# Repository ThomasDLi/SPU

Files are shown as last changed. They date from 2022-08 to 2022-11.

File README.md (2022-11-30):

# SPU (work in progress)
Sigma Processing Unit: an indelendently driveable 8-bit CPU designed by myself, inspired by the interface used to communicate with the 6502 microprocesser and Ben Eater's 8 bit cpu. I have also written an article on this project! https://thomasdli.notion.site/Designing-An-8-Bit-CPU-Thomas-Li-f7da20de04c84557adcc27d55567141a



(pcb)



(pcb layout)



(zoomed out screenshot of the schematic)

## Specs
- 8 bit address bus for a total of 256 memory locations (including program counter, which starts at address 0, and can also go up to 255)
- 8 bit data bus

- full 8 bit load immediate instructions supported

- 2 general purpose registers
- add/subtraction for ALU with conditional junps for both Zero and Carry flags

- 16 instructions avaliable currently with minimal edits required in order to increase up to 128 instructions
- 16 clock cycles required for each instruction

- R/W flag for memory

- support for external I/O

- turing complete

- maximum clock speed of idfk

### instruction set

- still writing firmware

## todo

- write firmware
- design a VIA for the processor for I/O

## downloading design

This CPU was designed using 74LS series ICs from Texas Instruments, and was made using Autodesk Eagle.

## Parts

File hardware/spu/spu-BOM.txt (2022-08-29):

Partlist exported from /Users/thomas/Documents/EAGLE/projects/spu/spu-schematic.sch at 2022-08-28 8:30 PM

Part    Value    Device    Package Description                          POPULARITY
ADDRESS          PINHD-1X8 1X08    PIN HEADER                           67        
DATA             PINHD-1X8 1X08    PIN HEADER                           67        
HALT             PINHD-1X1 1X01    PIN HEADER                           64        
IC1     74LS173N 74LS173N  DIL16   4-bit D type REGISTER, 3-state       0         
IC2     74LS173N 74LS173N  DIL16   4-bit D type REGISTER, 3-state       0         
IC3     74LS173N 74LS173N  DIL16   4-bit D type REGISTER, 3-state       0         
IC4     74LS173N 74LS173N  DIL16   4-bit D type REGISTER, 3-state       0         
IC5     74AC245N 74AC245N  DIL20   Octal BUS TRANSCEIVER, 3-state       0         
IC6     74AC245N 74AC245N  DIL20   Octal BUS TRANSCEIVER, 3-state       0         
IC7     74LS173N 74LS173N  DIL16   4-bit D type REGISTER, 3-state       0         
IC8     74LS173N 74LS173N  DIL16   4-bit D type REGISTER, 3-state       0         
IC9     74AC245N 74AC245N  DIL20   Octal BUS TRANSCEIVER, 3-state       0         
IC10    74AC245N 74AC245N  DIL20   Octal BUS TRANSCEIVER, 3-state       0         
IC11    74LS86N  74LS86N   DIL14   Quad 2-input EXCLUSIVE-OR (XOR) gate 0         
IC12    74LS283N 74LS283N  DIL16   4-bit binary FULL ADDER, fast carry  0         
IC13    74LS283N 74LS283N  DIL16   4-bit binary FULL ADDER, fast carry  0         
IC14    74LS86N  74LS86N   DIL14   Quad 2-input EXCLUSIVE-OR (XOR) gate 0         
IC15    74LS173N 74LS173N  DIL16   4-bit D type REGISTER, 3-state       0         
IC16    74S02N   74S02N    DIL14   Quad 2-input NOR gate                0         
IC17    74LS08N  74LS08N   DIL14   Quad 2-input AND gate                0         
IC18    74AC245N 74AC245N  DIL20   Octal BUS TRANSCEIVER, 3-state       0         
IC19    74LS173N 74LS173N  DIL16   4-bit D type REGISTER, 3-state       0         
IC20    74LS173N 74LS173N  DIL16   4-bit D type REGISTER, 3-state       0         
IC21    74AC245N 74AC245N  DIL20   Octal BUS TRANSCEIVER, 3-state       0         
IC22    74LS161  74HCT160N DIL16   Synchronous 4-bit COUNTER            0         
IC23    74LS161  74HCT160N DIL16   Synchronous 4-bit COUNTER            0         
IC24    74LS173N 74LS173N  DIL16   4-bit D type REGISTER, 3-state       0         
IC25    74LS173N 74LS173N  DIL16   4-bit D type REGISTER, 3-state       0         
IC26    74AC245N 74AC245N  DIL20   Octal BUS TRANSCEIVER, 3-state       0         
IC27    74LS04N  74LS04N   DIL14   Hex INVERTER                         0         
IC28    74LS04N  74LS04N   DIL14   Hex INVERTER                         0         
IC29    74LS04N  74LS04N   DIL14   Hex INVERTER                         0         
IC30    74LS161  74HC160N  DIL16   Synchronous 4-bit COUNTER            0         
IC31    74LS04N  74LS04N   DIL14   Hex INVERTER                         0         
JP2     CLOCK/RW PINHD-1X2 1X02    PIN HEADER                           98        
POWER   5V/GND   PINHD-1X2 1X02    PIN HEADER                           98        
U1      AT28C256 AT28C256  DIL28-6 EEPROM 32Kx8 256k bit                          
U2      AT28C256 AT28C256  DIL28-6 EEPROM 32Kx8 256k bit                          
U3      AT28C256 AT28C256  DIL28-6 EEPROM 32Kx8 256k bit

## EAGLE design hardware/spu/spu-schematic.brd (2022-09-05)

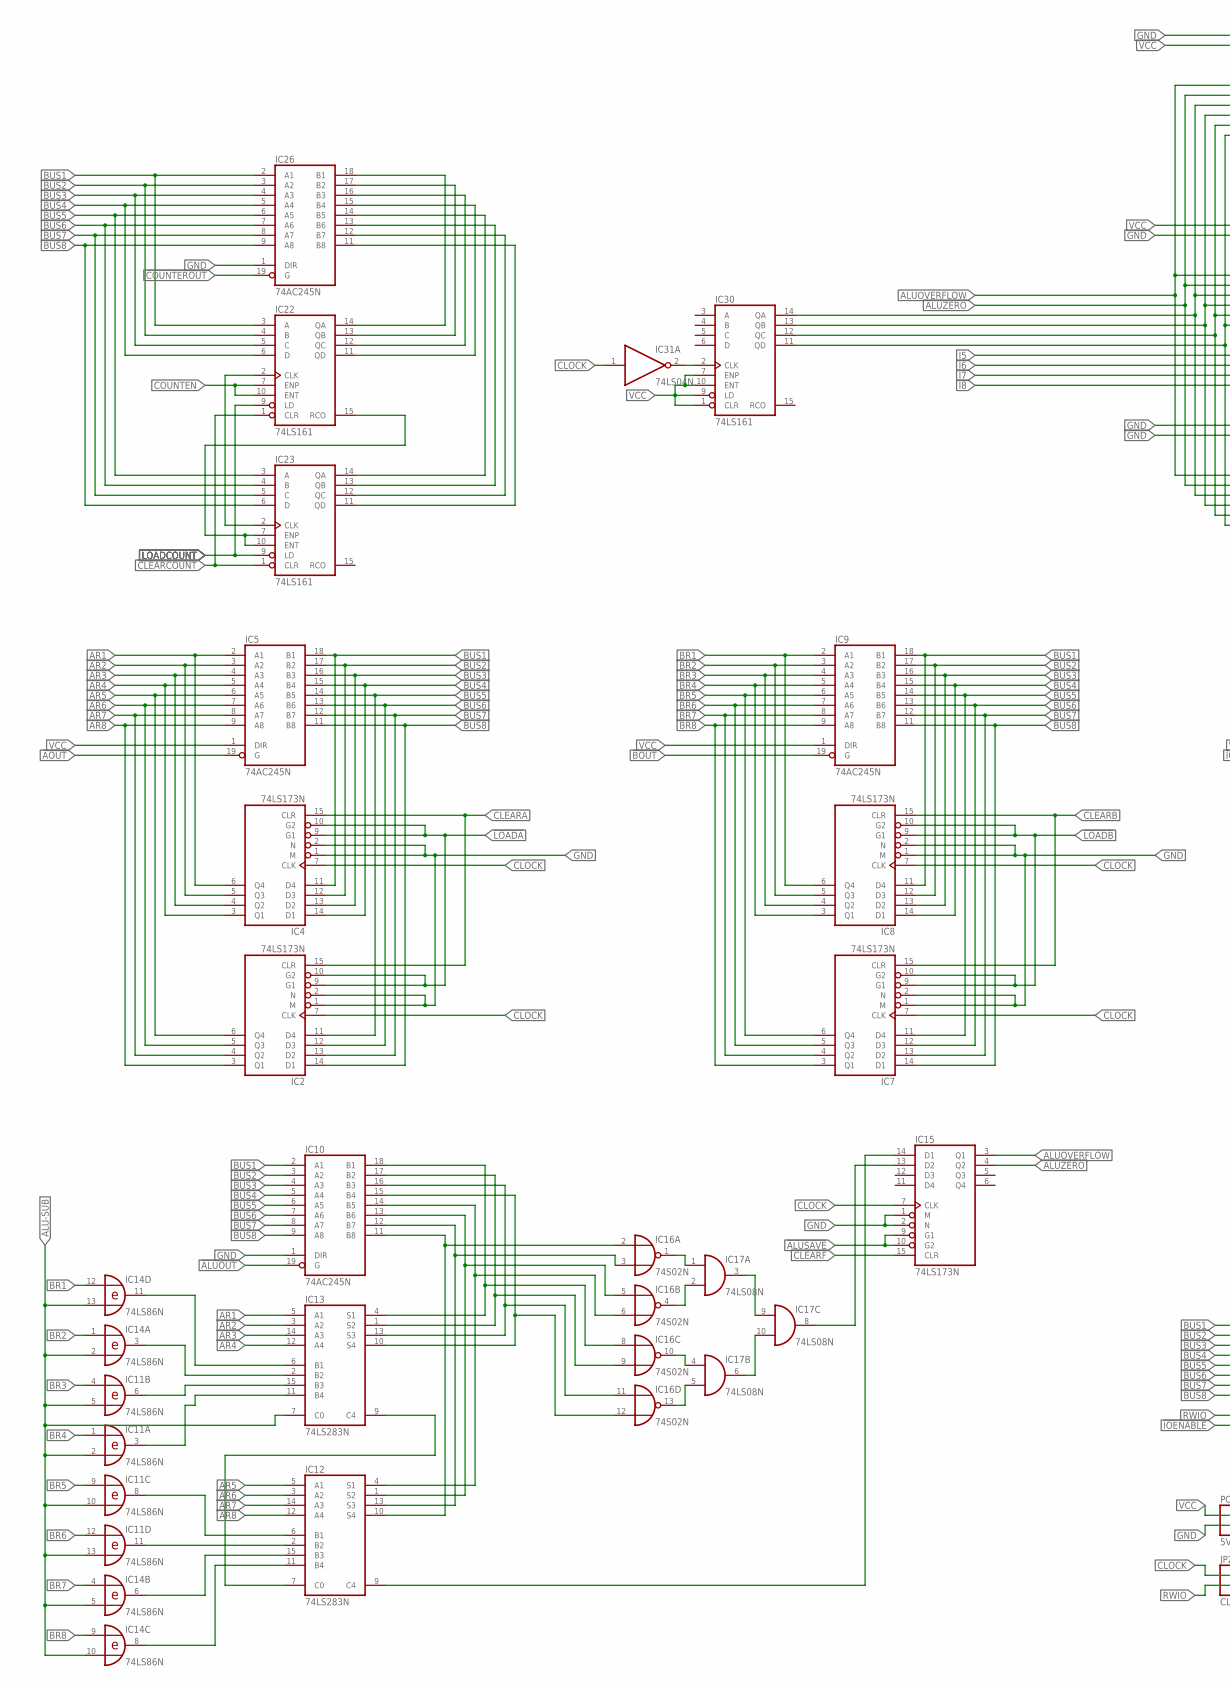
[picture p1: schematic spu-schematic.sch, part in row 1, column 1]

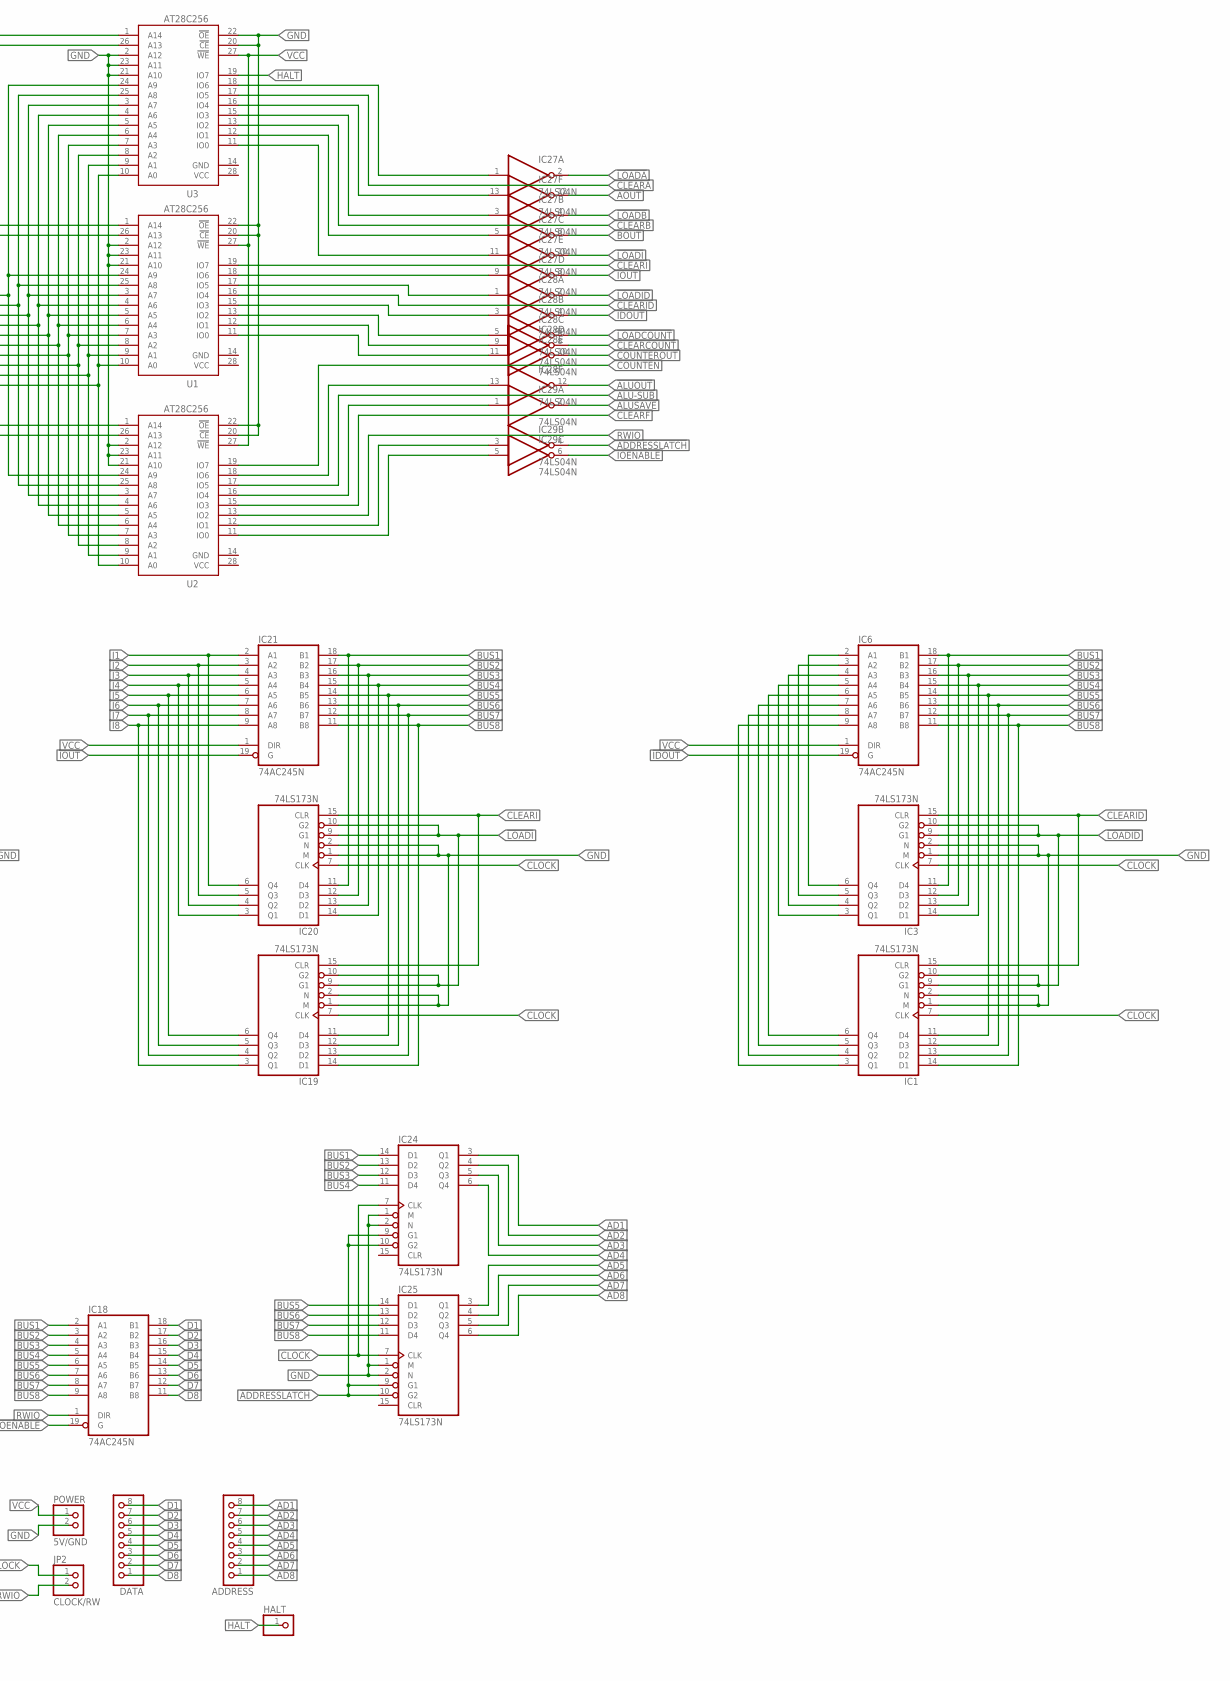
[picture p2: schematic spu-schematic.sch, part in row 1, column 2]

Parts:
ADDRESS: PINHD-1X8; 1X08
DATA: PINHD-1X8; 1X08
HALT: PINHD-1X1; 1X01
IC1, IC2, IC3, IC4, IC7, IC8, IC15, IC19, IC20, IC24, IC25: 74LS173N; DIL16
IC5, IC6, IC9, IC10, IC18, IC21, IC26: 74AC245N; DIL20
IC11, IC14: 74LS86N; DIL14
IC12, IC13: 74LS283N; DIL16
IC16: 74S02N; DIL14
IC17: 74LS08N; DIL14
IC22, IC23, IC30: 74LS161; DIL16
IC27, IC28, IC29, IC31: 74LS04N; DIL14
JP2: CLOCK/RW; 1X02
POWER: 5V/GND; 1X02
U1, U2, U3: AT28C256; DIL28-6

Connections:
!ADDRESSLATCH: IC24.9 (G1), IC24.10 (G2), IC25.9 (G1), IC25.10 (G2), IC29.4 (O)
!ALUOUT: IC10.19 (G), IC28.12 (O)
!ALUSAVE: IC15.9 (G1), IC15.10 (G2), IC29.2 (O)
!AOUT: IC5.19 (G), IC27.12 (O)
!BOUT: IC9.19 (G), IC27.6 (O)
!CLEARCOUNT: IC22.1 (CLR), IC23.1 (CLR), IC28.8 (O)
!COUNTEROUT: IC26.19 (G), IC28.10 (O)
!IDOUT: IC6.19 (G), IC28.4 (O)
!IOENABLE: IC18.19 (G), IC29.6 (O)
!IOUT: IC21.19 (G), IC27.8 (O)
!LOADA: IC2.9 (G1), IC2.10 (G2), IC4.9 (G1), IC4.10 (G2), IC27.2 (O)
!LOADB: IC7.9 (G1), IC7.10 (G2), IC8.9 (G1), IC8.10 (G2), IC27.4 (O)
!LOADCOUNT: IC22.9 (LD), IC23.9 (LD), IC28.6 (O)
!LOADI: IC19.9 (G1), IC19.10 (G2), IC20.9 (G1), IC20.10 (G2), IC27.10 (O)
!LOADID: IC1.9 (G1), IC1.10 (G2), IC3.9 (G1), IC3.10 (G2), IC28.2 (O)
AD1: ADDRESS.8, IC24.3 (Q1)
AD2: ADDRESS.7, IC24.4 (Q2)
AD3: ADDRESS.6, IC24.5 (Q3)
AD4: ADDRESS.5, IC24.6 (Q4)
AD5: ADDRESS.4, IC25.3 (Q1)
AD6: ADDRESS.3, IC25.4 (Q2)
AD7: ADDRESS.2, IC25.5 (Q3)
AD8: ADDRESS.1, IC25.6 (Q4)
ALU-SUB: IC11.2 (I1), IC11.5 (I1), IC11.10 (I1), IC11.13 (I1), IC13.7 (C0), IC14.2 (I1), IC14.5 (I1), IC14.10 (I1), IC14.13 (I1), U2.17 (IO5)
ALUOVERFLOW: IC15.3 (Q1), U1.24 (A9), U2.24 (A9), U3.24 (A9)
ALUZERO: IC15.4 (Q2), U1.25 (A8), U2.25 (A8), U3.25 (A8)
AR1: IC4.6 (Q4), IC5.2 (A1), IC13.5 (A1)
AR2: IC4.5 (Q3), IC5.3 (A2), IC13.3 (A2)
AR3: IC4.4 (Q2), IC5.4 (A3), IC13.14 (A3)
AR4: IC4.3 (Q1), IC5.5 (A4), IC13.12 (A4)
AR5: IC2.6 (Q4), IC5.6 (A5), IC12.5 (A1)
AR6: IC2.5 (Q3), IC5.7 (A6), IC12.3 (A2)
AR7: IC2.4 (Q2), IC5.8 (A7), IC12.14 (A3)
AR8: IC2.3 (Q1), IC5.9 (A8), IC12.12 (A4)
BR1: IC8.6 (Q4), IC9.2 (A1), IC14.12 (I0)
BR2: IC8.5 (Q3), IC9.3 (A2), IC14.1 (I0)
BR3: IC8.4 (Q2), IC9.4 (A3), IC11.4 (I0)
BR4: IC8.3 (Q1), IC9.5 (A4), IC11.1 (I0)
BR5: IC7.6 (Q4), IC9.6 (A5), IC11.9 (I0)
BR6: IC7.5 (Q3), IC9.7 (A6), IC11.12 (I0)
BR7: IC7.4 (Q2), IC9.8 (A7), IC14.4 (I0)
BR8: IC7.3 (Q1), IC9.9 (A8), IC14.9 (I0)
BR9: IC3.6 (Q4), IC6.2 (A1)
BR10: IC3.5 (Q3), IC6.3 (A2)
BR11: IC3.4 (Q2), IC6.4 (A3)
BR12: IC3.3 (Q1), IC6.5 (A4)
BR13: IC1.5 (Q3), IC6.7 (A6)
BR14: IC1.6 (Q4), IC6.6 (A5)
BR15: IC1.4 (Q2), IC6.8 (A7)
BR16: IC1.3 (Q1), IC6.9 (A8)
BUS1: IC3.11 (D4), IC4.11 (D4), IC5.18 (B1), IC6.18 (B1), IC8.11 (D4), IC9.18 (B1), IC10.2 (A1), IC18.2 (A1), IC20.11 (D4), IC21.18 (B1), IC22.3 (A), IC24.14 (D1), IC26.2 (A1)
BUS2: IC3.12 (D3), IC4.12 (D3), IC5.17 (B2), IC6.17 (B2), IC8.12 (D3), IC9.17 (B2), IC10.3 (A2), IC18.3 (A2), IC20.12 (D3), IC21.17 (B2), IC22.4 (B), IC24.13 (D2), IC26.3 (A2)
BUS3: IC3.13 (D2), IC4.13 (D2), IC5.16 (B3), IC6.16 (B3), IC8.13 (D2), IC9.16 (B3), IC10.4 (A3), IC18.4 (A3), IC20.13 (D2), IC21.16 (B3), IC22.5 (C), IC24.12 (D3), IC26.4 (A3)
BUS4: IC3.14 (D1), IC4.14 (D1), IC5.15 (B4), IC6.15 (B4), IC8.14 (D1), IC9.15 (B4), IC10.5 (A4), IC18.5 (A4), IC20.14 (D1), IC21.15 (B4), IC22.6 (D), IC24.11 (D4), IC26.5 (A4)
BUS5: IC1.11 (D4), IC2.11 (D4), IC5.14 (B5), IC6.14 (B5), IC7.11 (D4), IC9.14 (B5), IC10.6 (A5), IC18.6 (A5), IC19.11 (D4), IC21.14 (B5), IC23.3 (A), IC25.14 (D1), IC26.6 (A5)
BUS6: IC1.12 (D3), IC2.12 (D3), IC5.13 (B6), IC6.13 (B6), IC7.12 (D3), IC9.13 (B6), IC10.7 (A6), IC18.7 (A6), IC19.12 (D3), IC21.13 (B6), IC23.4 (B), IC25.13 (D2), IC26.7 (A6)
BUS7: IC1.13 (D2), IC2.13 (D2), IC5.12 (B7), IC6.12 (B7), IC7.13 (D2), IC9.12 (B7), IC10.8 (A7), IC18.8 (A7), IC19.13 (D2), IC21.12 (B7), IC23.5 (C), IC25.12 (D3), IC26.8 (A7)
BUS8: IC1.14 (D1), IC2.14 (D1), IC5.11 (B8), IC6.11 (B8), IC7.14 (D1), IC9.11 (B8), IC10.9 (A8), IC18.9 (A8), IC19.14 (D1), IC21.11 (B8), IC23.6 (D), IC25.11 (D4), IC26.9 (A8)
CLEARA: IC2.15 (CLR), IC4.15 (CLR), U3.17 (IO5)
CLEARB: IC7.15 (CLR), IC8.15 (CLR), U3.13 (IO2)
CLEARF: IC15.15 (CLR), U2.15 (IO3)
CLEARI: IC19.15 (CLR), IC20.15 (CLR), U1.19 (IO7)
CLEARID: IC1.15 (CLR), IC3.15 (CLR), U1.16 (IO4)
CLOCK: IC1.7 (CLK), IC2.7 (CLK), IC3.7 (CLK), IC4.7 (CLK), IC7.7 (CLK), IC8.7 (CLK), IC15.7 (CLK), IC19.7 (CLK), IC20.7 (CLK), IC24.7 (CLK), IC25.7 (CLK), IC30.2 (CLK), IC31.1 (I), IC31.2 (O), JP2.1
COUNTEN: IC22.7 (ENP), IC22.10 (ENT), U2.19 (IO7)
D1: DATA.8, IC18.18 (B1)
D2: DATA.7, IC18.17 (B2)
D3: DATA.6, IC18.16 (B3)
D4: DATA.5, IC18.15 (B4)
D5: DATA.4, IC18.14 (B5)
D6: DATA.3, IC18.13 (B6)
D7: DATA.2, IC18.12 (B7)
D8: DATA.1, IC18.11 (B8)
GND: IC1.1 (M), IC1.2 (N), IC1.8 (GND), IC2.1 (M), IC2.2 (N), IC2.8 (GND), IC3.1 (M), IC3.2 (N), IC3.8 (GND), IC4.1 (M), IC4.2 (N), IC4.8 (GND), IC5.10 (GND), IC6.10 (GND), IC7.1 (M), IC7.2 (N), IC7.8 (GND), IC8.1 (M), IC8.2 (N), IC8.8 (GND), IC9.10 (GND), IC10.1 (DIR), IC10.10 (GND), IC11.7 (GND), IC12.8 (GND), IC13.8 (GND), IC14.7 (GND), IC15.1 (M), IC15.2 (N), IC15.8 (GND), IC16.7 (GND), IC17.7 (GND), IC18.10 (GND), IC19.1 (M), IC19.2 (N), IC19.8 (GND), IC20.1 (M), IC20.2 (N), IC20.8 (GND), IC21.10 (GND), IC22.8 (GND), IC23.8 (GND), IC24.1 (M), IC24.2 (N), IC24.8 (GND), IC25.1 (M), IC25.2 (N), IC25.8 (GND), IC26.1 (DIR), IC26.10 (GND), IC27.7 (GND), IC28.7 (GND), IC29.7 (GND), IC30.8 (GND), IC31.7 (GND), POWER.2, U1.2 (A12), U1.20 (!CE), U1.21 (A10), U1.22 (!OE), U1.23 (A11), U1.26 (A13), U2.1 (A14), U2.2 (A12), U2.20 (!CE), U2.21 (A10), U2.22 (!OE), U2.23 (A11), U2.26 (A13), U3.1 (A14), U3.2 (A12), U3.20 (!CE), U3.21 (A10), U3.22 (!OE), U3.23 (A11)
HALT: HALT.1, U3.19 (IO7)
I1: IC20.6 (Q4), IC21.2 (A1)
I2: IC20.5 (Q3), IC21.3 (A2)
I3: IC20.4 (Q2), IC21.4 (A3)
I4: IC20.3 (Q1), IC21.5 (A4)
I5: IC19.6 (Q4), IC21.6 (A5), U1.7 (A3), U2.7 (A3), U3.7 (A3)
I6: IC19.5 (Q3), IC21.7 (A6), U1.8 (A2), U2.8 (A2), U3.8 (A2)
I7: IC19.4 (Q2), IC21.8 (A7), U1.9 (A1), U2.9 (A1), U3.9 (A1)
I8: IC19.3 (Q1), IC21.9 (A8), U1.10 (A0), U2.10 (A0), U3.10 (A0)
unnamed: IC12.7 (C0), IC13.9 (C4)
unnamed: IC12.11 (B4), IC14.8 (O)
unnamed: IC12.9 (C4), IC15.14 (D1)
unnamed: IC10.14 (B5), IC12.4 (S1), IC16.6 (I1)
unnamed: IC10.13 (B6), IC12.1 (S2), IC16.5 (I0)
unnamed: IC13.6 (B1), IC14.11 (O)
unnamed: IC13.2 (B2), IC14.3 (O)
unnamed: IC11.6 (O), IC13.15 (B3)
unnamed: IC11.3 (O), IC13.11 (B4)
unnamed: IC10.18 (B1), IC13.4 (S1), IC16.8 (I0)
unnamed: IC10.17 (B2), IC13.1 (S2), IC16.9 (I1)
unnamed: IC10.16 (B3), IC13.13 (S3), IC16.11 (I0)
unnamed: IC10.15 (B4), IC13.10 (S4), IC16.12 (I1)
unnamed: IC10.12 (B7), IC12.13 (S3), IC16.3 (I1)
unnamed: IC10.11 (B8), IC12.10 (S4), IC16.2 (I0)
unnamed: IC16.1 (O), IC17.1 (I0)
unnamed: IC22.15 (RCO), IC23.7 (ENP), IC23.10 (ENT)
unnamed: IC29.3 (I), U2.12 (IO1)
unnamed: IC22.2 (CLK), IC23.2 (CLK)
unnamed: IC29.5 (I), U2.11 (IO0)
unnamed: IC11.8 (O), IC12.6 (B1)
unnamed: IC11.11 (O), IC12.2 (B2)
unnamed: IC12.15 (B3), IC14.6 (O)
unnamed: IC22.14 (QA), IC26.18 (B1)
unnamed: IC22.13 (QB), IC26.17 (B2)
unnamed: IC16.4 (O), IC17.2 (I1)
unnamed: IC16.10 (O), IC17.4 (I0)
unnamed: IC16.13 (O), IC17.5 (I1)
unnamed: IC17.3 (O), IC17.9 (I0)
unnamed: IC17.6 (O), IC17.10 (I1)
unnamed: IC15.13 (D2), IC17.8 (O)
unnamed: IC22.12 (QC), IC26.16 (B3)
unnamed: IC22.11 (QD), IC26.15 (B4)
unnamed: IC23.14 (QA), IC26.14 (B5)
unnamed: IC23.13 (QB), IC26.13 (B6)
unnamed: IC23.12 (QC), IC26.12 (B7)
unnamed: IC23.11 (QD), IC26.11 (B8)
unnamed: IC29.1 (I), U2.16 (IO4)
unnamed: IC28.13 (I), U2.18 (IO6)
unnamed: IC28.11 (I), U1.11 (IO0)
unnamed: IC28.9 (I), U1.12 (IO1)
unnamed: IC28.5 (I), U1.13 (IO2)
unnamed: IC28.3 (I), U1.15 (IO3)
unnamed: IC28.1 (I), U1.17 (IO5)
unnamed: IC27.9 (I), U1.18 (IO6)
unnamed: IC27.11 (I), U3.11 (IO0)
unnamed: IC27.5 (I), U3.12 (IO1)
unnamed: IC27.3 (I), U3.15 (IO3)
unnamed: IC27.13 (I), U3.16 (IO4)
unnamed: IC27.1 (I), U3.18 (IO6)
unnamed: IC30.14 (QA), U1.3 (A7), U2.3 (A7), U3.3 (A7)
unnamed: IC30.13 (QB), U1.4 (A6), U2.4 (A6), U3.4 (A6)
unnamed: IC30.12 (QC), U1.5 (A5), U2.5 (A5), U3.5 (A5)
unnamed: IC30.11 (QD), U1.6 (A4), U2.6 (A4), U3.6 (A4)
RWIO: IC18.1 (DIR), JP2.2, U2.13 (IO2)
VCC: IC1.16 (VCC), IC2.16 (VCC), IC3.16 (VCC), IC4.16 (VCC), IC5.1 (DIR), IC5.20 (VCC), IC6.1 (DIR), IC6.20 (VCC), IC7.16 (VCC), IC8.16 (VCC), IC9.1 (DIR), IC9.20 (VCC), IC10.20 (VCC), IC11.14 (VCC), IC12.16 (VCC), IC13.16 (VCC), IC14.14 (VCC), IC15.16 (VCC), IC16.14 (VCC), IC17.14 (VCC), IC18.20 (VCC), IC19.16 (VCC), IC20.16 (VCC), IC21.1 (DIR), IC21.20 (VCC), IC22.16 (VCC), IC23.16 (VCC), IC24.16 (VCC), IC25.16 (VCC), IC26.20 (VCC), IC27.14 (VCC), IC28.14 (VCC), IC29.14 (VCC), IC30.1 (CLR), IC30.7 (ENP), IC30.9 (LD), IC30.10 (ENT), IC30.16 (VCC), IC31.14 (VCC), POWER.1, U1.1 (A14), U1.27 (!WE), U2.27 (!WE), U3.26 (A13), U3.27 (!WE)

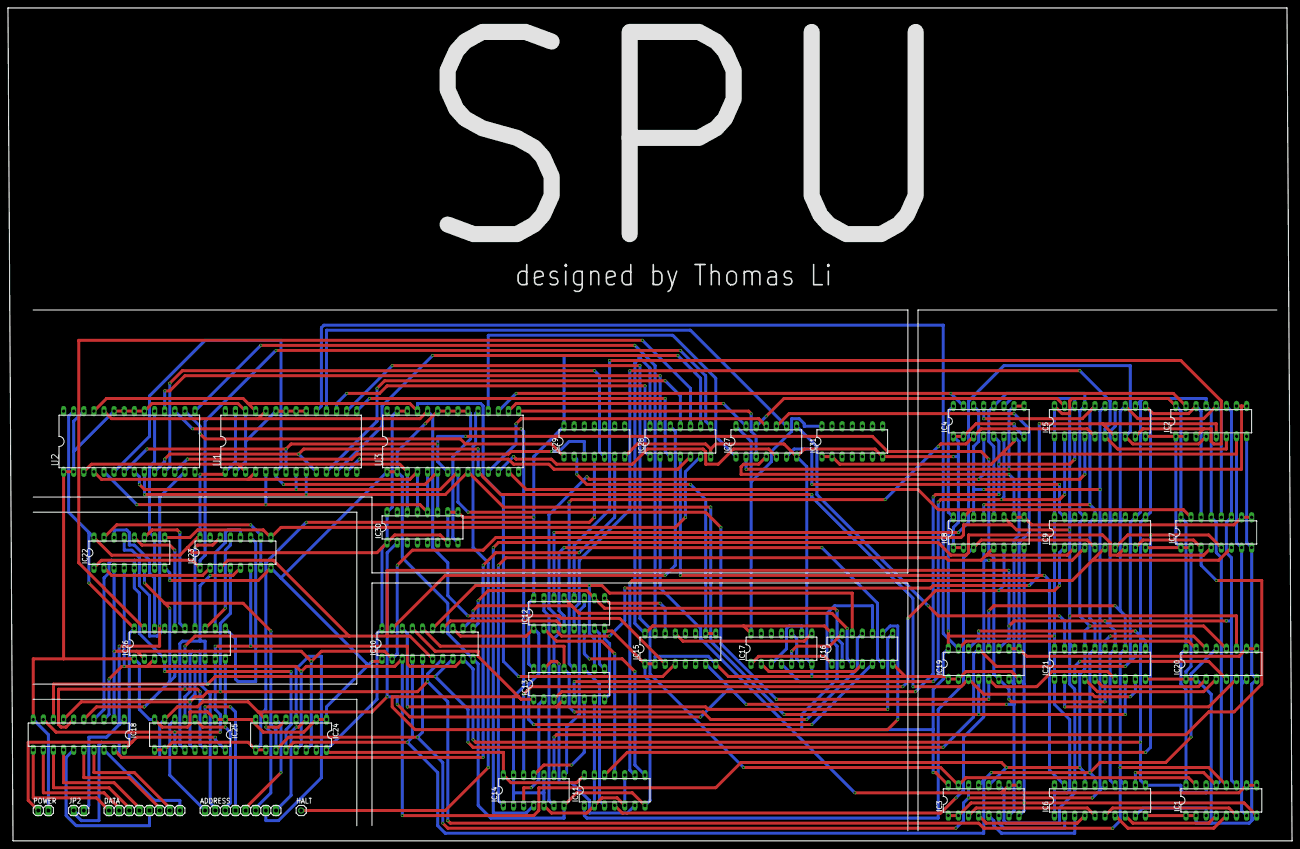
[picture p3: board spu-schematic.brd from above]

Board: 2 copper layers, 322.6 x 209.2 mm, 39 parts (0 on the bottom side), 139 nets.
